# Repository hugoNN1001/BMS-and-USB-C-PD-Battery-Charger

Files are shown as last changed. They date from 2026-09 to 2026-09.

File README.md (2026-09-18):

# What is it?

This is a **BMS board** I designed for UNSW Bluesat's Cubesat as part of the **Australian Universities Rocket Competition (AURC)** which takes place in September 2027.

The **USB-C PD charger** is implemented on a separate board due to time constraint before the competition deadline.

The **BQ7791501** is a 3-5 cell stackable, ultra-low power battery pack protector with autonomous cell-balancing and hibernate mode. **Hibernate mode** is important to conserve battery life during long transit and standby time until the launch signal.

<table>
  <tr>
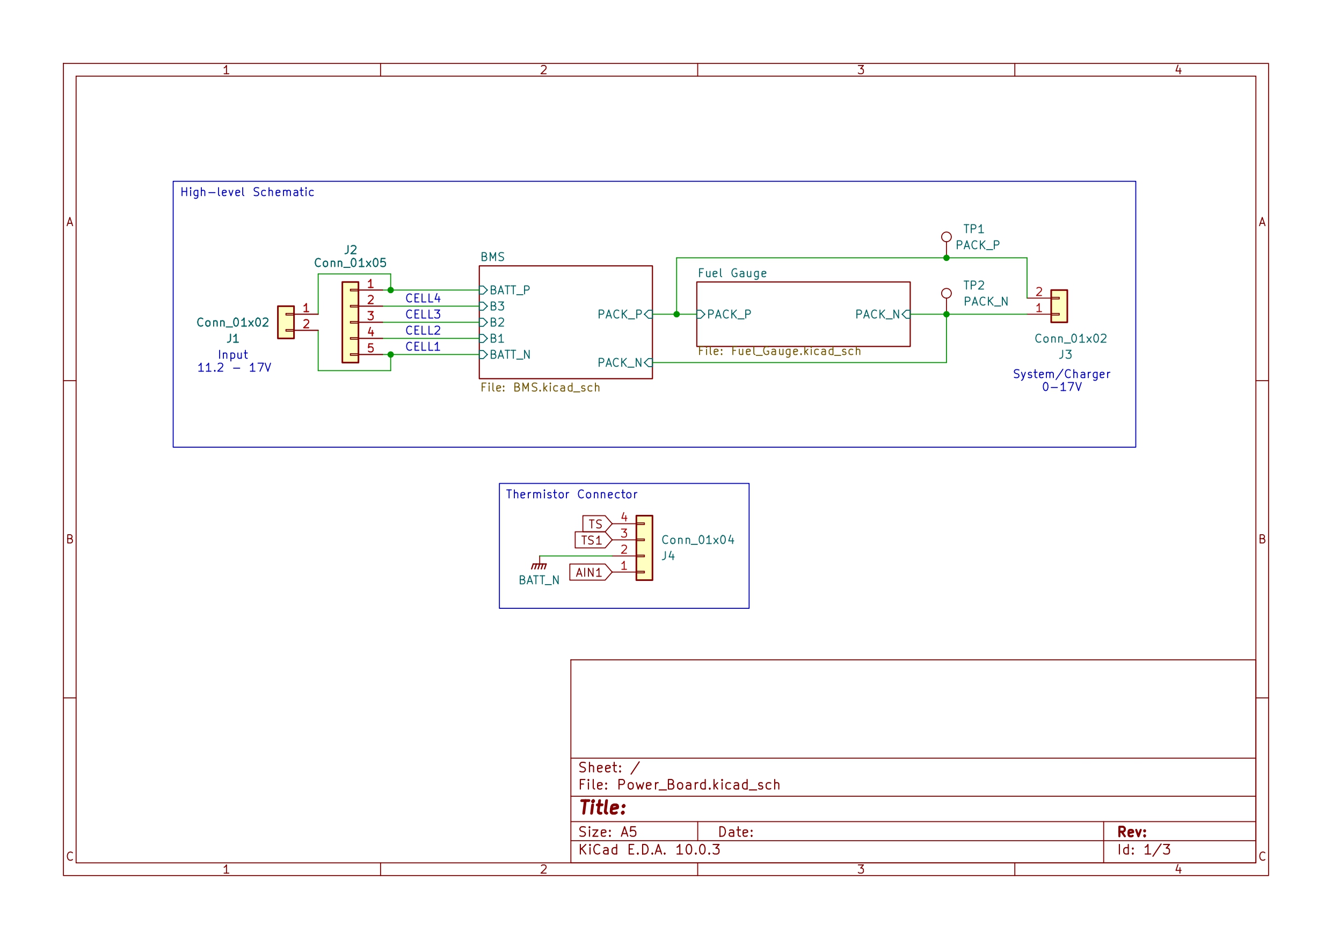
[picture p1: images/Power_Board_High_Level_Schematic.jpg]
    <td></td>
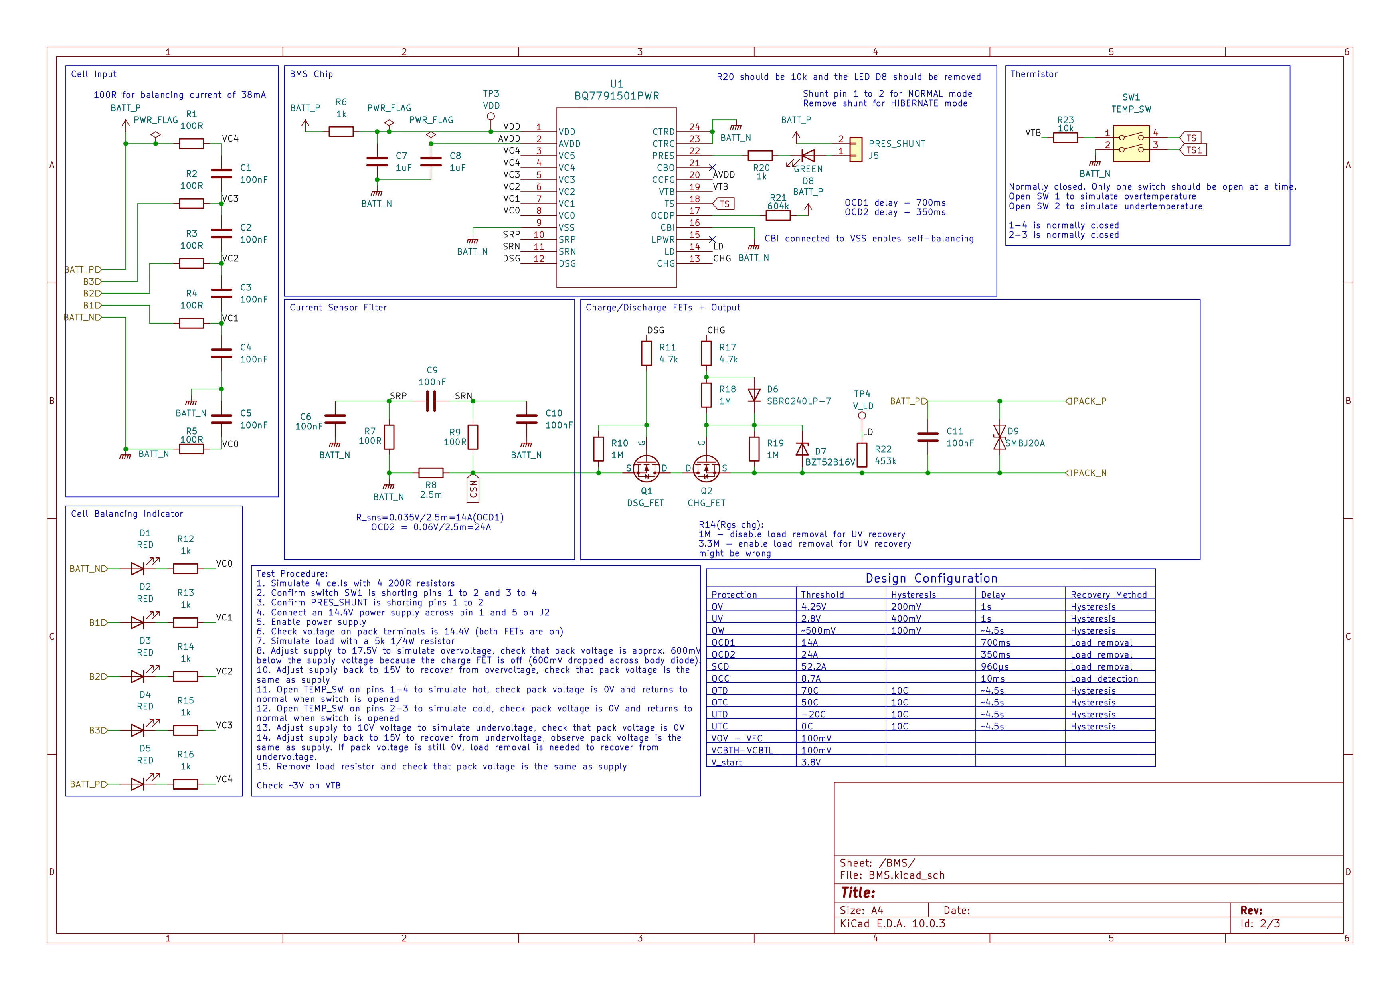
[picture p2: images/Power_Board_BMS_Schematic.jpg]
    <td></td>
  </tr>
  <tr>
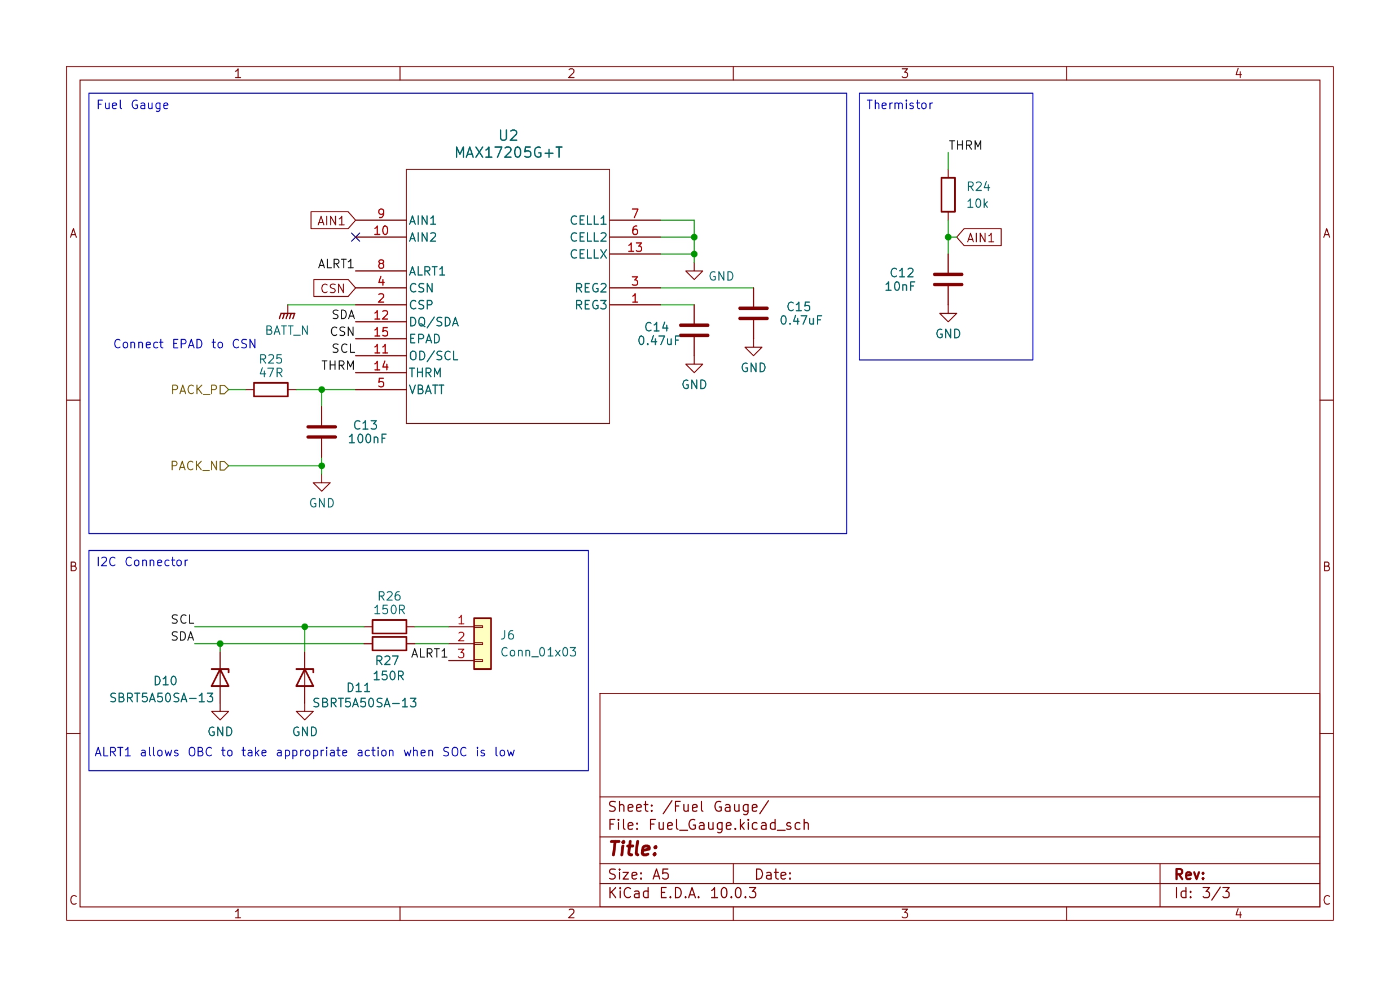
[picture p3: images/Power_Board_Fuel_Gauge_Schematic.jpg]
    <td></td>
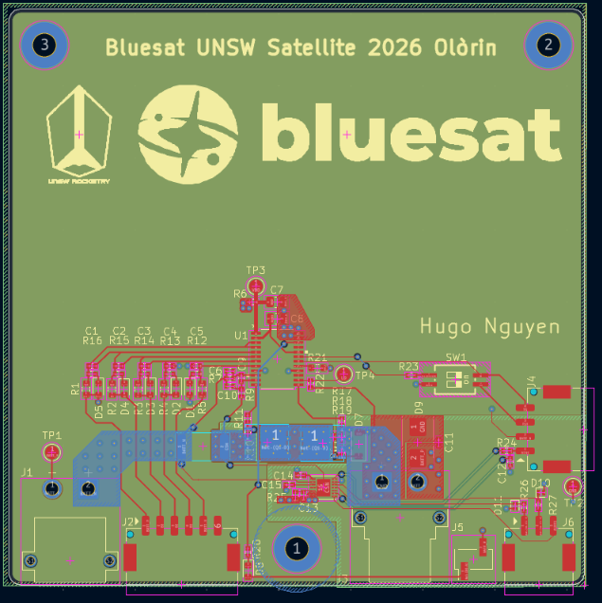
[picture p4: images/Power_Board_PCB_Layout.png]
    <td></td>
  </tr>
  <tr>
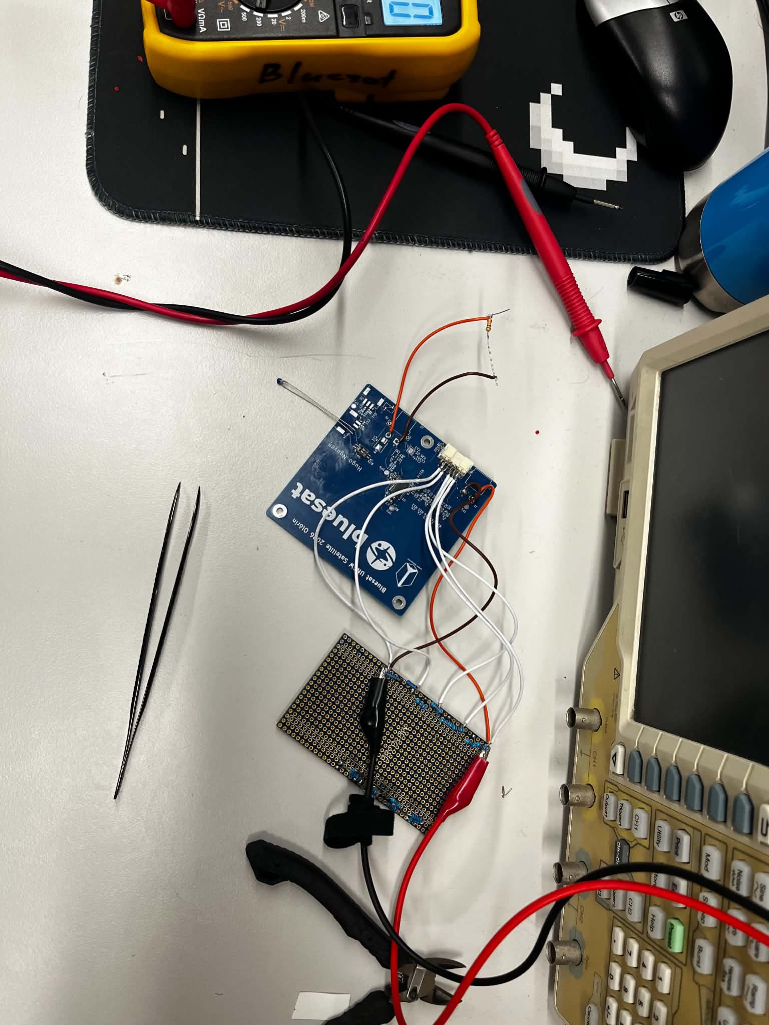
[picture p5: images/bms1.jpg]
    <td></td>
    <td></td>
  </tr>
</table>

## Technical

The two main loads are:
- **32 UV LEDs** to cure the resin of the Cubesat's 3D printer payload: In the worst-case, where battery pack voltage is near cut-off and LEDs are at set to output max power, they will draw around **8.5A** continuously
- **Stepper motor**: draws around 0.86A continuously and 1.06A peak

-> **Total current = 8.5A + 1.06A = 9.56A**

**OC1** is set to be **14A at 700ms**, this was chosen due to availability of the sense resistor values and should give us **~30% margin**. However, there is a tolerance of **± 20%** so it could be anywhere between **11.2A to 16.8A**.

**OC2**, as a result, is set at **24A at 350ms**.

The sense resistor is **2.5 mOhms with 0.5% tolerance** (instead of the regular 1%) for accurate current reading. **Kelvin connection** was used so the 2 sense traces carry minimum current. It is also rated up to **3W**, which is well above the calculated power dissipation of **1.44W** at OCD2 current of 24A.

A pair of switches was added to simulate a **hot/cold condition**, which assists in verifying the proper working of the BMS.

A **filter network** was placed close to the sense pins of the protector IC helps to filter noise out of the current reading.

A **jumper shunt** can be removed to enter **hibernate mode**.

## Status

The BMS board is working, **thoroughly verified**, in particular **OV, UV, OTD, UTD, OTC, UTC**.

**OCD1, OCD2, and OCC** is to be verified by using a larger sense resistor value to lower the overcurrent threshold. It is currently too high for the power supply's output current capability.

**Cell-balancing** has also been verified to work.

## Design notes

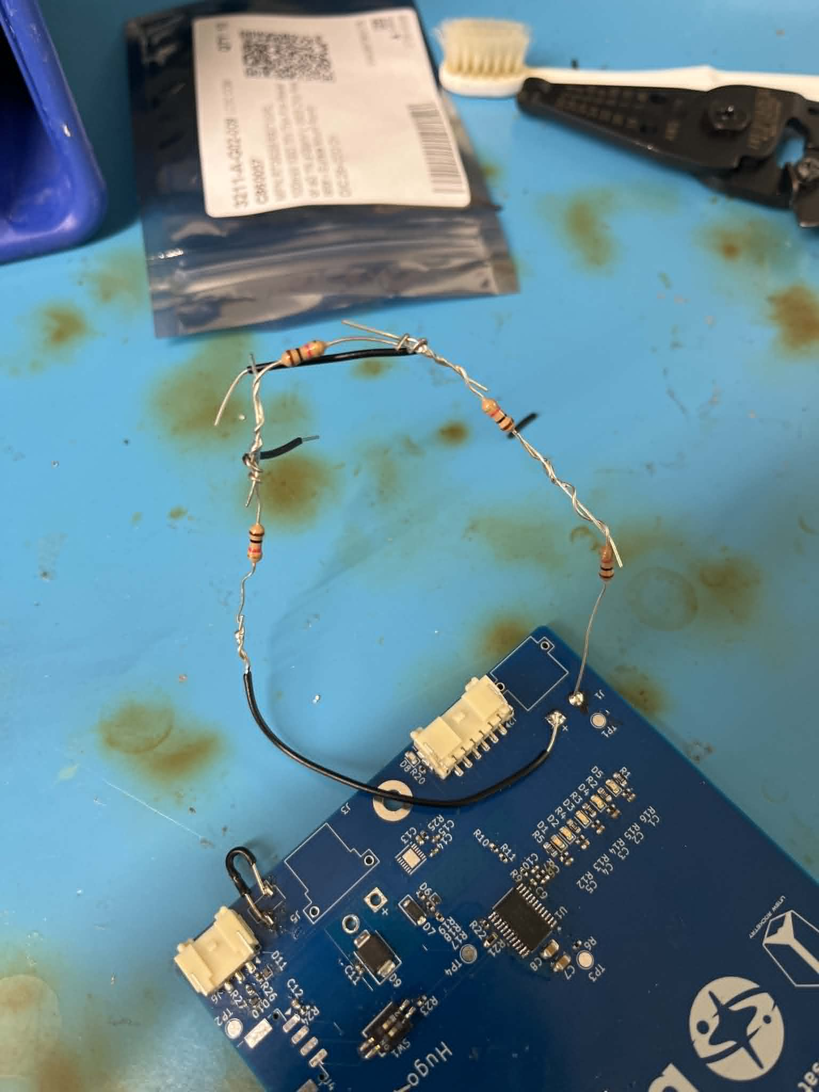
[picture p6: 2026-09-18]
images/bms4.jpg

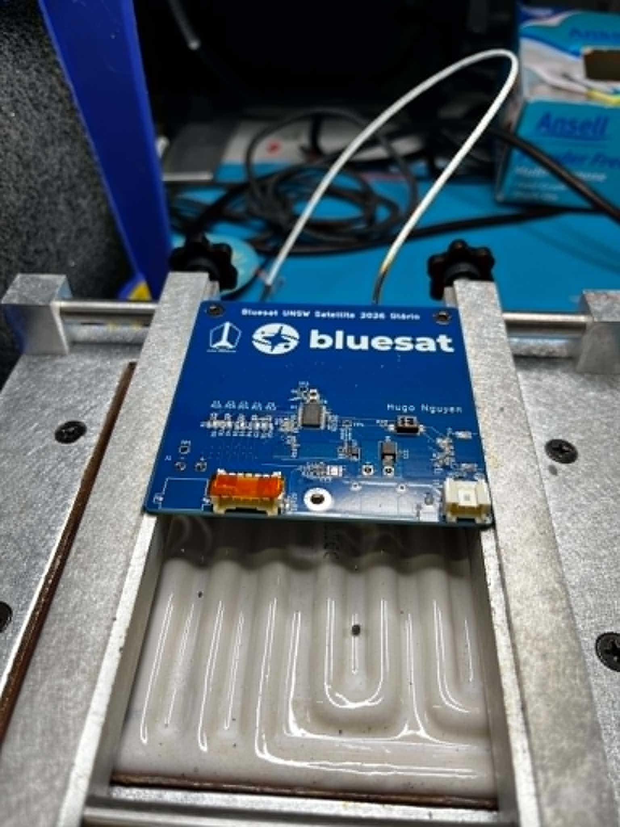
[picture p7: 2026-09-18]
images/bms5.jpg

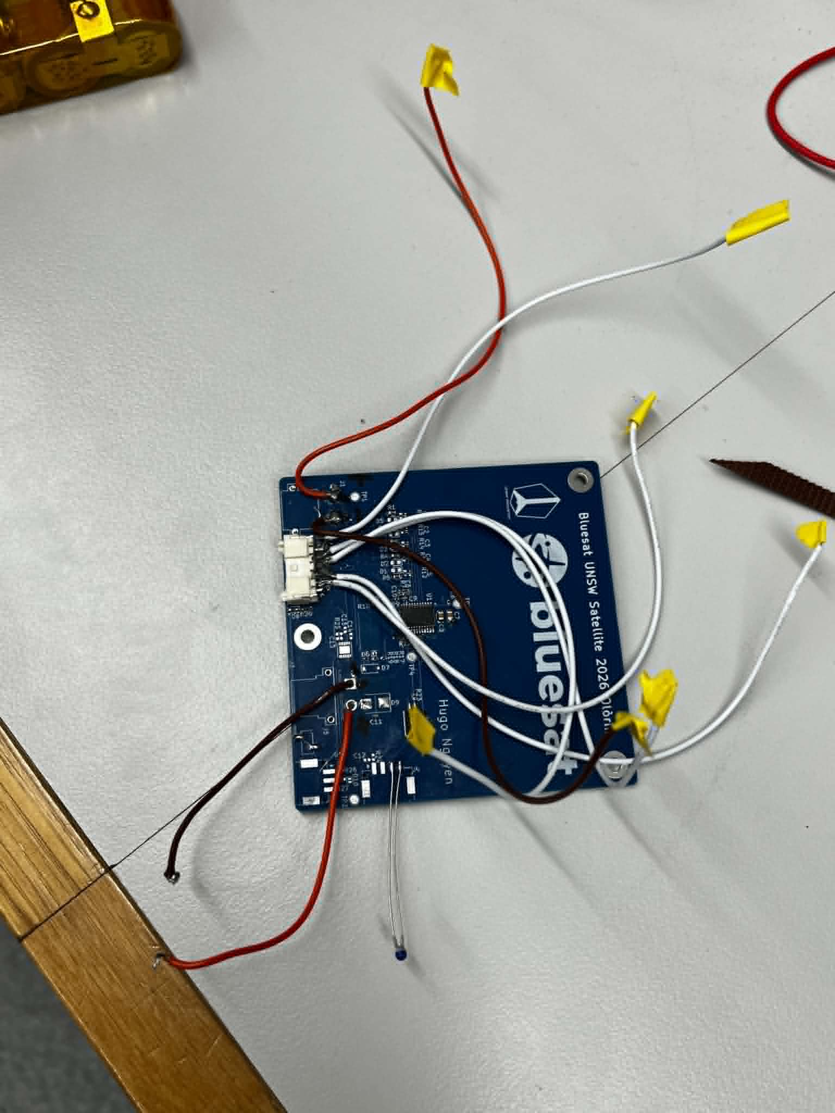
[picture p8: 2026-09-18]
images/bms2.jpg

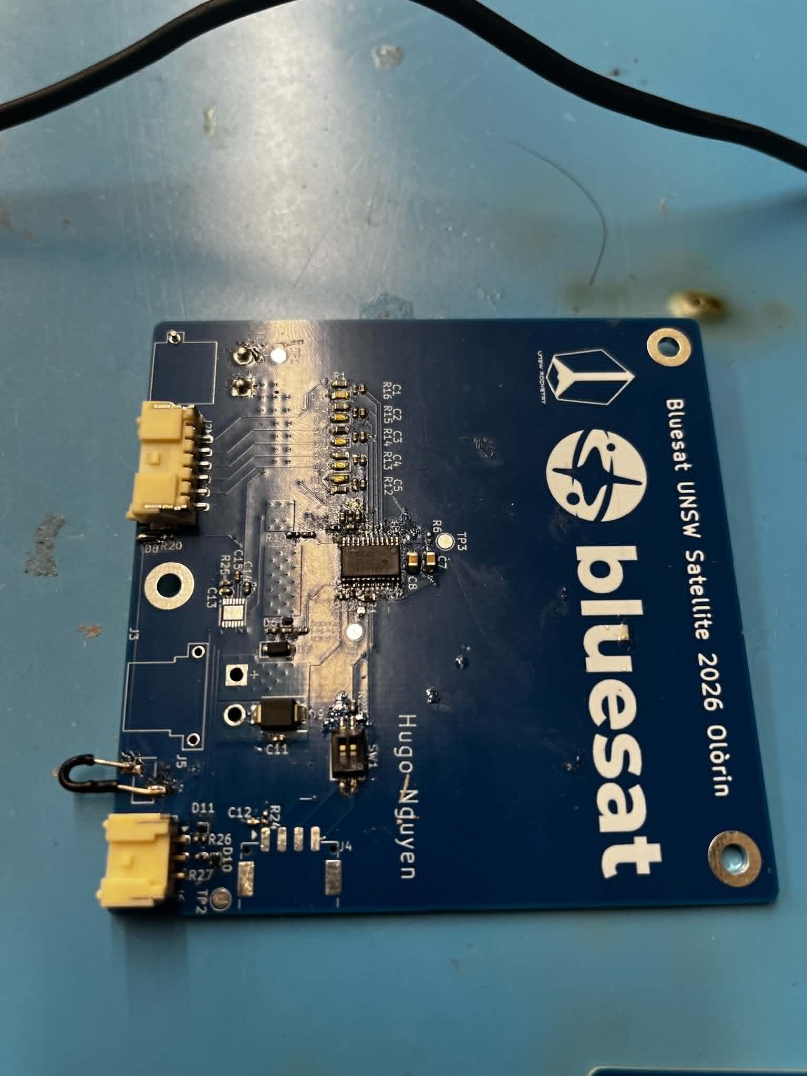
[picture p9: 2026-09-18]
images/bms3.jpg

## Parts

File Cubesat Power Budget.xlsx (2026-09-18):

Subsystem | Device | Component | Rail (V) | Quantity | Typ Current (mA) | Max Current (mA) | Ave Power (mW) |  | Note
Motor |  |  |  | Number of Phases | Phase Current (mA) | Max Current (mA) | Dissipated Power (mW) | Phase Resistant (Ω)
 |  |  |  | 2 | 1400 | 462 | 5174.4 | 2.64
Motor Total |  |  |  |  | 2800 | 924 | 10348.8 | 5.28
OBC
 | MCU | STM32G474RB | 3.3 | 1 |  |  | 0
 | Accelerometer | H3LIS331DL | 3.3 | 1 | 0.37 | 0.37 | 1.221 |  | ODR = 1000Hz
 | Barometer | BMP585 | 3.3 | 1 | 0.08 | 0.08 | 0.264
 | Temp Sensor | TMP1075D | 3.3 | 1 | 0.01 | 0.01 | 0.033 |  | SCL freq = 400kHz (fast mode)
 | Stepper Motor Driver |  |  |  |  |  | 0
 | GNSS | SAM-M10Q | 3.3 | 1 | 14.3 | 14.3 | 47.19
OBC Total
UV LCD Board |  |  |  |  |  | Estimated current drawn for 2*16 LEDs |  | add some redundency
 | LED Drivers & LEDS |  |  |  |  | 7.567567568 |  | 8A | https://www.ti.com/lit/ds/symlink/tlc5940.pdf
 |  |  |  |  |  |  |  |  | This is not accounting for dimming the LEDS
UV LCD Board Total
Number of Cells:
4
Cell Min Voltage:
2.8
 |  |  |  | https://www.littelfuse.com/media?itemid=75e32973-b177-4ee3-a0ff-cedaf1abdb93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
 |  |  | D9 | TVS diode | C364296 | not in stock
 |  |  | D7 | D7: Zener - 16V | C18195337 | not in stock
 |  |  | D6 | D6 | C460742
 |  |  |  | thermistor (0402) | C77131 | thermister (thru-hole) | C511390 | not in stock
 |  |  |  | sense resistor | C49164684 | not in stock |  | mouser | Yageo | 603-PA2512FKF7T0R004
 |  |  |  | 604k | C2484614 | not in stock
 |  |  |  | 450k | C5159688 | not in stock
 |  |  |  | nmos | C67862
 |  |  |  | low rds on
 |  |  |  | vgs
 |  |  |  | Id > ~15A
 |  |  |  | Vds > 16.8V
 |  |  |  | fuel gauge ic | C7220642 | not in stock
 |  |  |  | 470nF | C92361 | not in stock

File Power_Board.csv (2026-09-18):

Reference | Qty | Value | DNP | Exclude from BOM | Exclude from Board | Footprint | Datasheet
C1,C2,C3,C4,C5,C6,C9,C10,C11,C13 | 10 | 100nF |  |  |  | Capacitor_SMD:C_0603_1608Metric
C7,C8 | 2 | 1uF |  |  |  | Capacitor_SMD:C_0805_2012Metric
C12 | 1 | 10nF |  |  |  | Capacitor_SMD:C_0402_1005Metric
C14,C15 | 2 | 0.47uF |  |  |  | Capacitor_SMD:C_0603_1608Metric
D1,D2,D3,D4,D5 | 5 | RED |  |  |  | LED_SMD:LED_0402_1005Metric
D6 | 1 | SBR0240LP-7 |  |  |  | Diode_SMD:D_SOD-882
D7 | 1 | BZT52B16V |  |  |  | Diode_SMD:D_SOD-123
D8 | 1 | GREEN |  |  |  | LED_SMD:LED_0603_1608Metric
D9 | 1 | SMBJ20A |  |  |  | Diode_SMD:D_SMB | https://www.littelfuse.com/media?itemid=75e32973-b177-4ee3-a0ff-cedaf1abdb93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
D10,D11 | 2 | SBRT5A50SA-13 |  |  |  | Diode_SMD:D_SOD-882
J1 | 1 | Conn_01x02 |  |  |  | Footprint_Lib:AMASS_XT30PW-F
J2,J5 | 2 | Conn_01x03 |  |  |  | Footprint_Lib:SM03B-PASS
J3 | 1 | Conn_01x02 |  |  |  | Footprint_Lib:AMASS_XT30PW-M
J4 | 1 | Conn_01x02 |  |  |  | Connector_PinHeader_2.54mm:PinHeader_1x02_P2.54mm_Vertical_SMD_Pin1Left
Q1 | 1 | DSG_FET |  |  |  | Footprint_Lib:PQFN_5x6mm_E_DGS | https://ngspice.sourceforge.io/docs/ngspice-html-manual/manual.xhtml#cha_MOSFETs
Q2 | 1 | CHG_FET |  |  |  | Footprint_Lib:PQFN_5x6mm_E_DGS | https://ngspice.sourceforge.io/docs/ngspice-html-manual/manual.xhtml#cha_MOSFETs
R1,R2,R3,R4,R5,R7,R9 | 7 | 100R |  |  |  | Resistor_SMD:R_0402_1005Metric
R6,R12,R13,R14,R15,R16,R17,R20 | 8 | 1k |  |  |  | Resistor_SMD:R_0402_1005Metric
R8 | 1 | 2.5m |  |  |  | Resistor_SMD:R_2512_6332Metric
R10,R18,R19 | 3 | 1M |  |  |  | Resistor_SMD:R_0402_1005Metric
R11 | 1 | 4.7k |  |  |  | Resistor_SMD:R_0402_1005Metric
R21 | 1 | 604k |  |  |  | Resistor_SMD:R_0402_1005Metric
R22 | 1 | 450k |  |  |  | Resistor_SMD:R_0402_1005Metric
R23,R24 | 2 | 10k |  |  |  | Resistor_SMD:R_0402_1005Metric
R25 | 1 | 47R |  |  |  | Resistor_SMD:R_0402_1005Metric
R26,R27 | 2 | 150R |  |  |  | Resistor_SMD:R_0402_1005Metric
SW1 | 1 | SW_DIP_x02 |  |  |  | Footprint_Lib:XUNPU DSHP-02-TS-GER
TH1,TH2 | 2 | NCP15XH103F03RC |  |  |  | Resistor_SMD:R_0402_1005Metric
TP1 | 1 | PACK_P |  |  |  | TestPoint:TestPoint_Pad_D2.0mm
TP2 | 1 | PACK_N |  |  |  | TestPoint:TestPoint_Pad_D2.0mm
TP3 | 1 | V_BATT |  |  |  | TestPoint:TestPoint_Pad_D2.0mm
TP4 | 1 | AVDD |  |  |  | TestPoint:TestPoint_Pad_D2.0mm
TP5 | 1 | VDD |  |  |  | TestPoint:TestPoint_Pad_D2.0mm
TP6 | 1 | V_LD |  |  |  | TestPoint:TestPoint_Pad_D2.0mm
TP7 | 1 | VTS |  |  |  | TestPoint:TestPoint_Pad_D2.0mm
U1 | 1 | BQ7791501PWR |  |  |  | Footprint_Lib:TSSOP24_PW_TEX | https://www.ti.com/lit/gpn/bq77915
U2 | 1 | MAX17205G+T |  |  |  | Footprint_Lib:21-0137_T1433-2C_MXM | MAX17205G+T

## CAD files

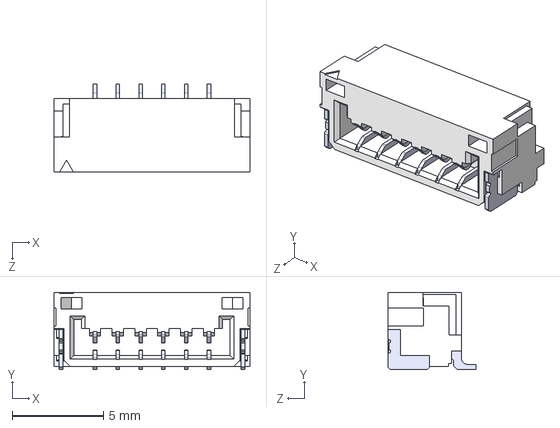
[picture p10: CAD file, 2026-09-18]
Power_Board_Misc/3D_Models/SM06B-GHS-TB.step
10.8 x 4.25 x 4.85 mm
SMxB-GHS-TB_06
pin x 6

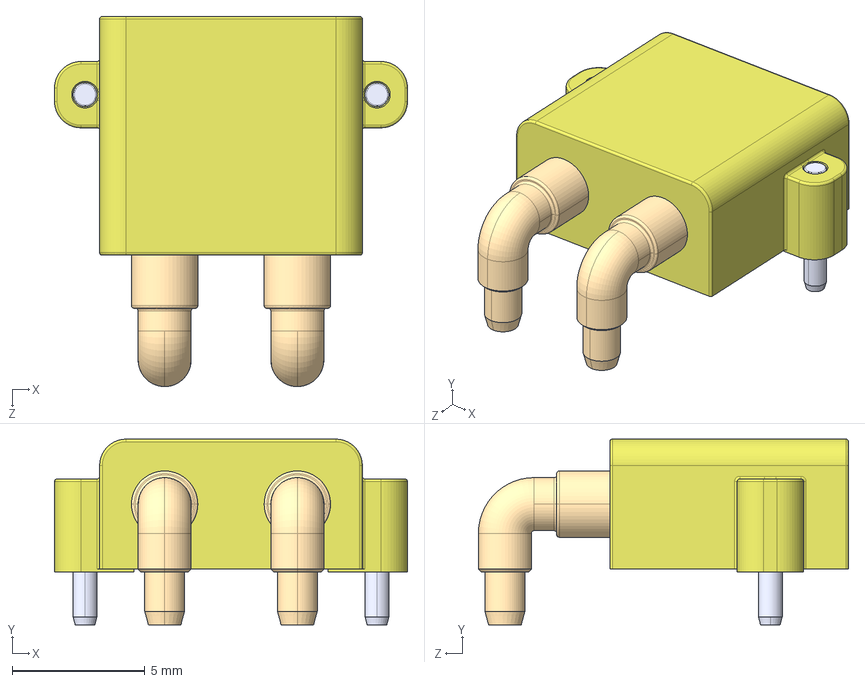
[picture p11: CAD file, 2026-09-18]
Power_Board_Misc/3D_Models/XT30PW-M.step
13.3 x 7.00 x 14.0 mm

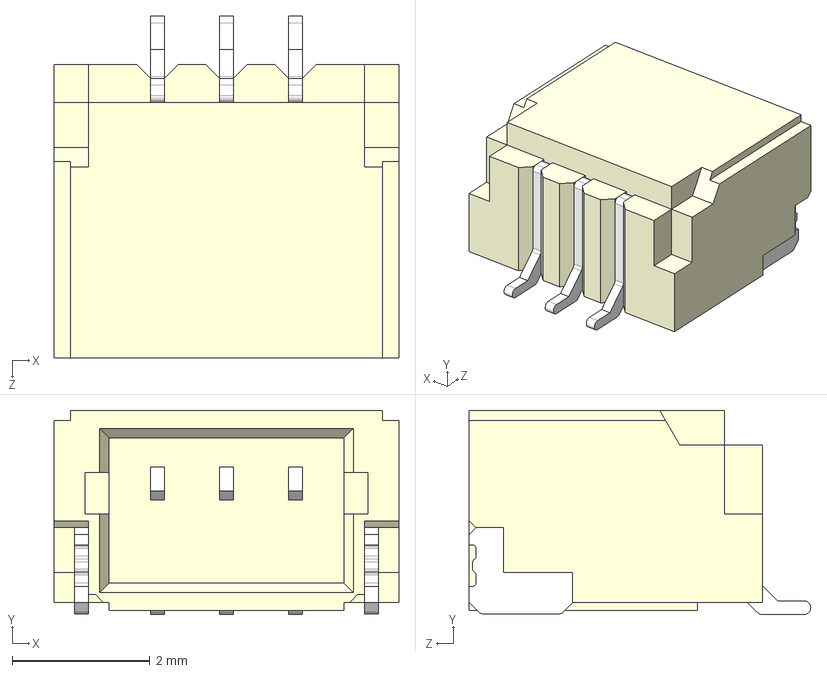
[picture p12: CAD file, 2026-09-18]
Power_Board_Misc/3D_Models/SM03B-SRSS-TB(LF)(SN)--3DModel-STEP-56544.STEP
5.00 x 2.96 x 4.95 mm

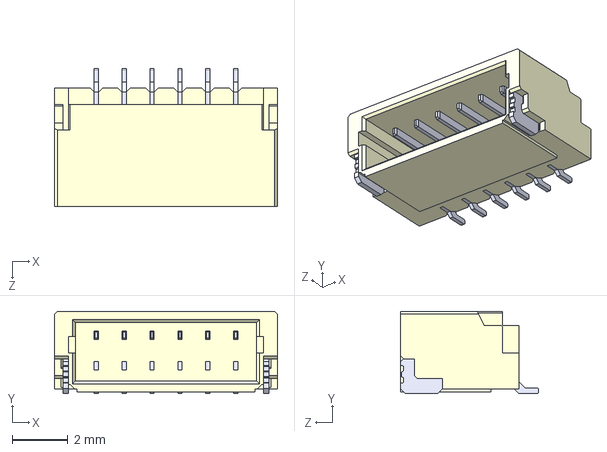
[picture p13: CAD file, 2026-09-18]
Power_Board_Misc/3D_Models/SM06B-SRSS-TB(LF)(SN)--3DModel-STEP-269445.STEP
8.00 x 2.95 x 4.95 mm

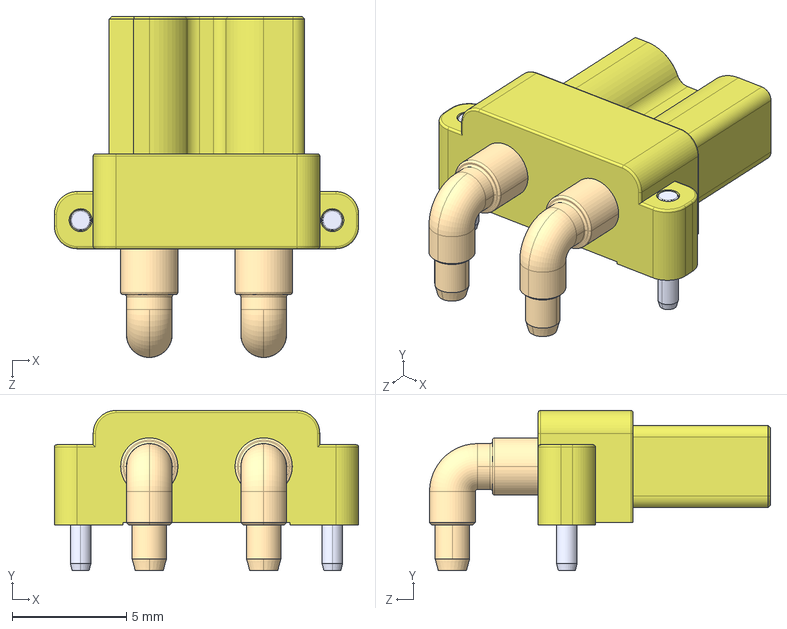
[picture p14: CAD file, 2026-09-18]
Power_Board_Misc/3D_Models/XT30PW-F.step
13.3 x 7.00 x 14.9 mm

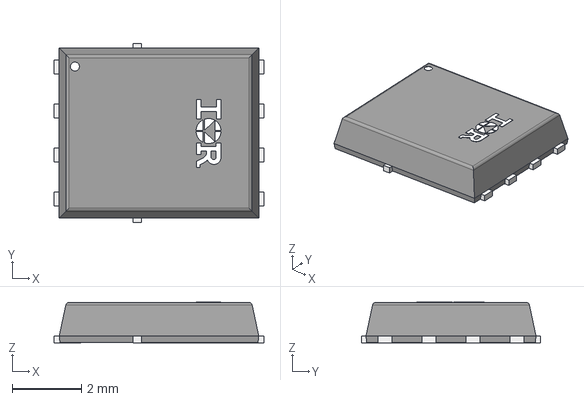
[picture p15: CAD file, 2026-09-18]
Power_Board_Misc/3D_Models/infineon-pg-tdson-8-907-3d-stp-package-en (1).stp
6.05 x 5.15 x 1.18 mm

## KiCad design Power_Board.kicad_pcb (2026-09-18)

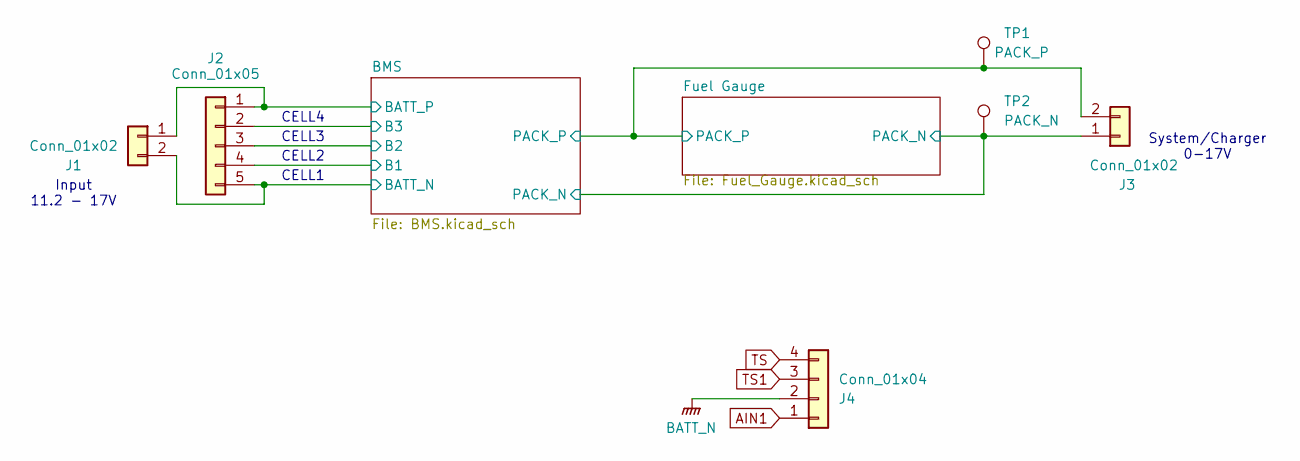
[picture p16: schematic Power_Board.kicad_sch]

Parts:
J1: Conn_01x02; AMASS_XT30PW-M
J2: Conn_01x05; SM06B-PASS
J3: Conn_01x02; AMASS_XT30PW-F
J4: Conn_01x04; SM04B-PASS
TP1: PACK_P; TestPoint_Pad_D2.0mm
TP2: PACK_N; TestPoint_Pad_D2.0mm

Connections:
/BMS/B1: J2.4; also elsewhere on the board
/BMS/B2: J2.3; also elsewhere on the board
/BMS/B3: J2.2; also elsewhere on the board
AIN1: J4.1; also elsewhere on the board
BATT_N: J1.2, J2.5, J4.2; also elsewhere on the board
BATT_P: J1.1, J2.1, J3.2, TP1.1 (1_1); also elsewhere on the board
GND: J3.1, TP2.1 (1_1); also elsewhere on the board
TS: J4.4; also elsewhere on the board
TS1: J4.3; also elsewhere on the board

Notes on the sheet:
CELL4
CELL3
CELL1
CELL2
System/Charger 0-17V
Input 11.2 - 17V

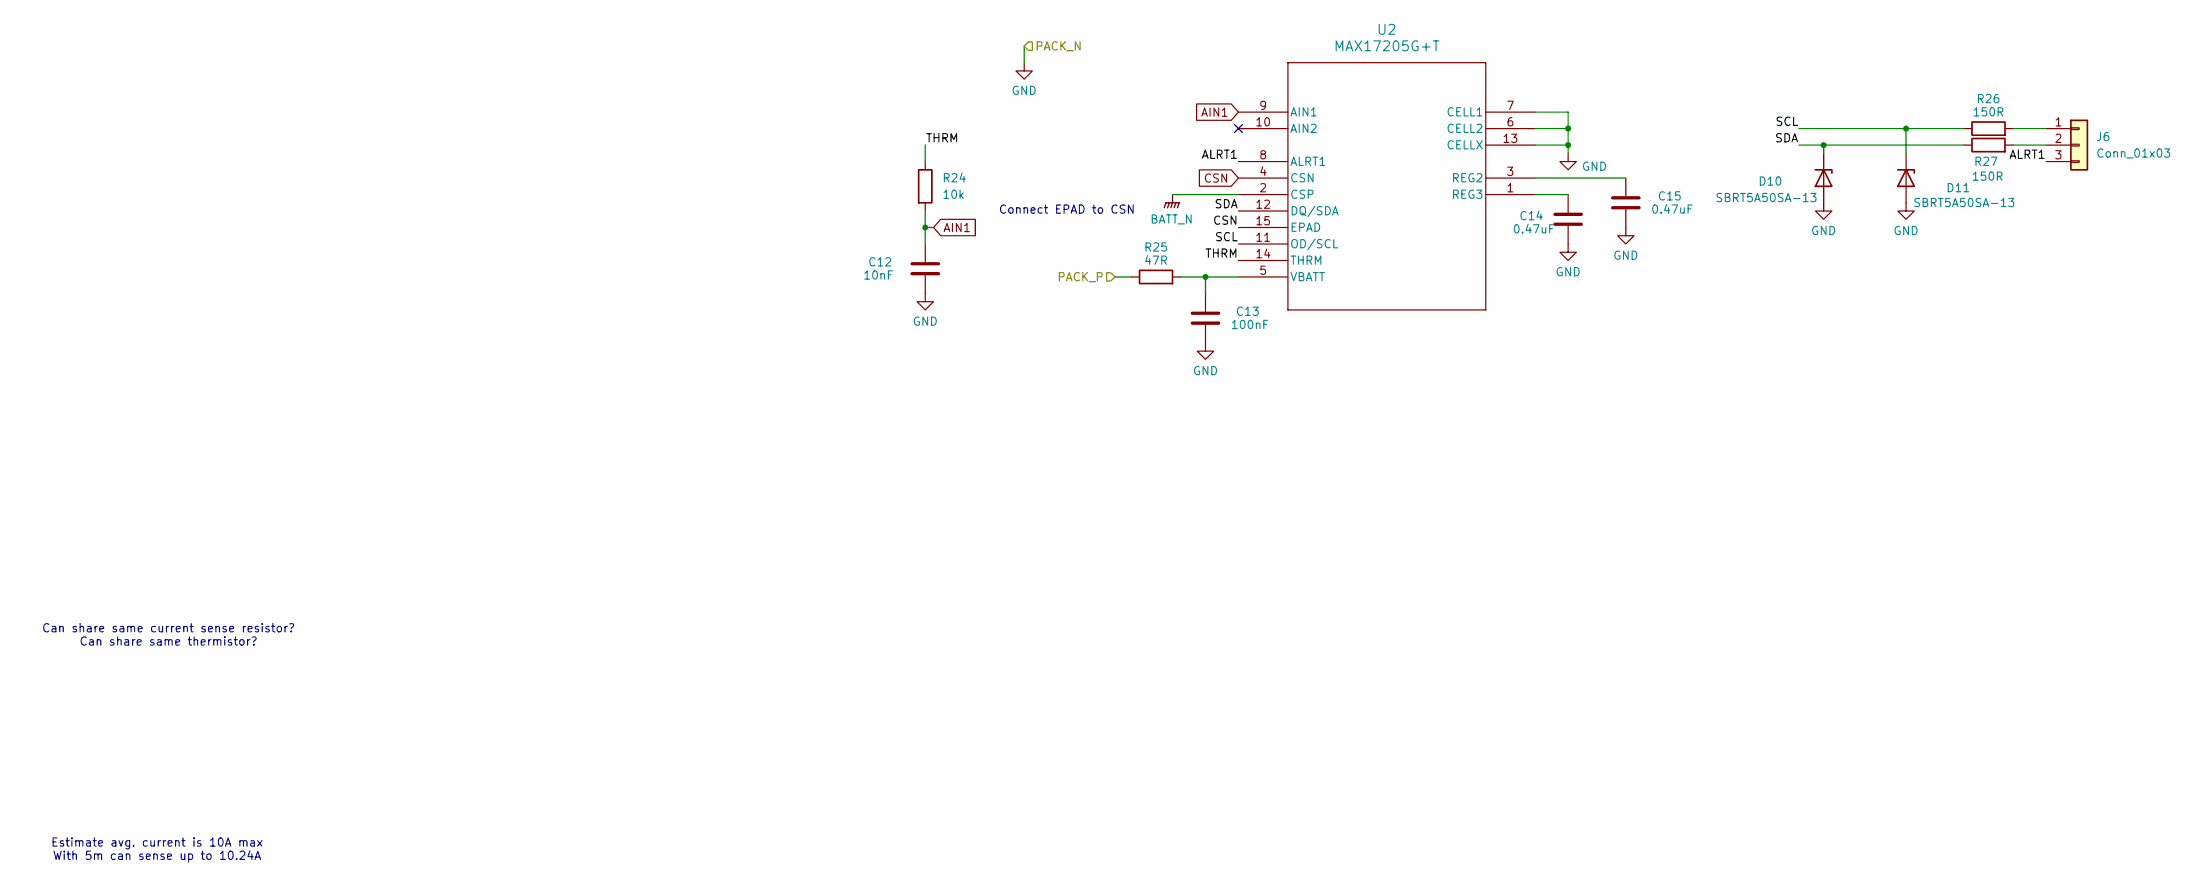
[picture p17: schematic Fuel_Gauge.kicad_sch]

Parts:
C12: 10nF; C_0402_1005Metric
C13: 100nF; C_0402_1005Metric
C14, C15: 0.47uF; C_0402_1005Metric
D10, D11: SBRT5A50SA-13; D_SOD-882
J6: Conn_01x03; SM03B-PASS
R24: 10k; R_0402_1005Metric
R25: 47R; R_0402_1005Metric
R26, R27: 150R; R_0402_1005Metric
U2: MAX17205G+T; 21-0137_T1433-2C_MXM

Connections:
/Fuel Gauge/ALRT1: J6.3, U2.8 (ALRT1)
/Fuel Gauge/SCL: D11.1 (K), R26.1, U2.11 (OD/SCL)
/Fuel Gauge/SDA: D10.1 (K), R27.1, U2.12 (DQ/SDA)
/Fuel Gauge/THRM: R24.1, U2.14 (THRM)
AIN1: C12.1, R24.2, U2.9 (AIN1); also elsewhere on the board
BATT_N: U2.2 (CSP); also elsewhere on the board
BATT_P: R25.1; also elsewhere on the board
CSN: U2.4 (CSN), U2.15 (EPAD); also elsewhere on the board
GND: C12.2, C13.2, C14.2, C15.2, D10.2 (A), D11.2 (A), U2.6 (CELL2), U2.7 (CELL1), U2.13 (CELLX); also elsewhere on the board
unnamed: J6.1, R26.2
unnamed: J6.2, R27.2
unnamed: C15.1, U2.3 (REG2)
unnamed: C14.1, U2.1 (REG3)
unnamed: C13.1, R25.2, U2.5 (VBATT)

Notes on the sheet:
Connect EPAD to CSN
Can share same current sense resistor? Can share same thermistor?
Estimate avg. current is 10A max With 5m can sense up to 10.24A

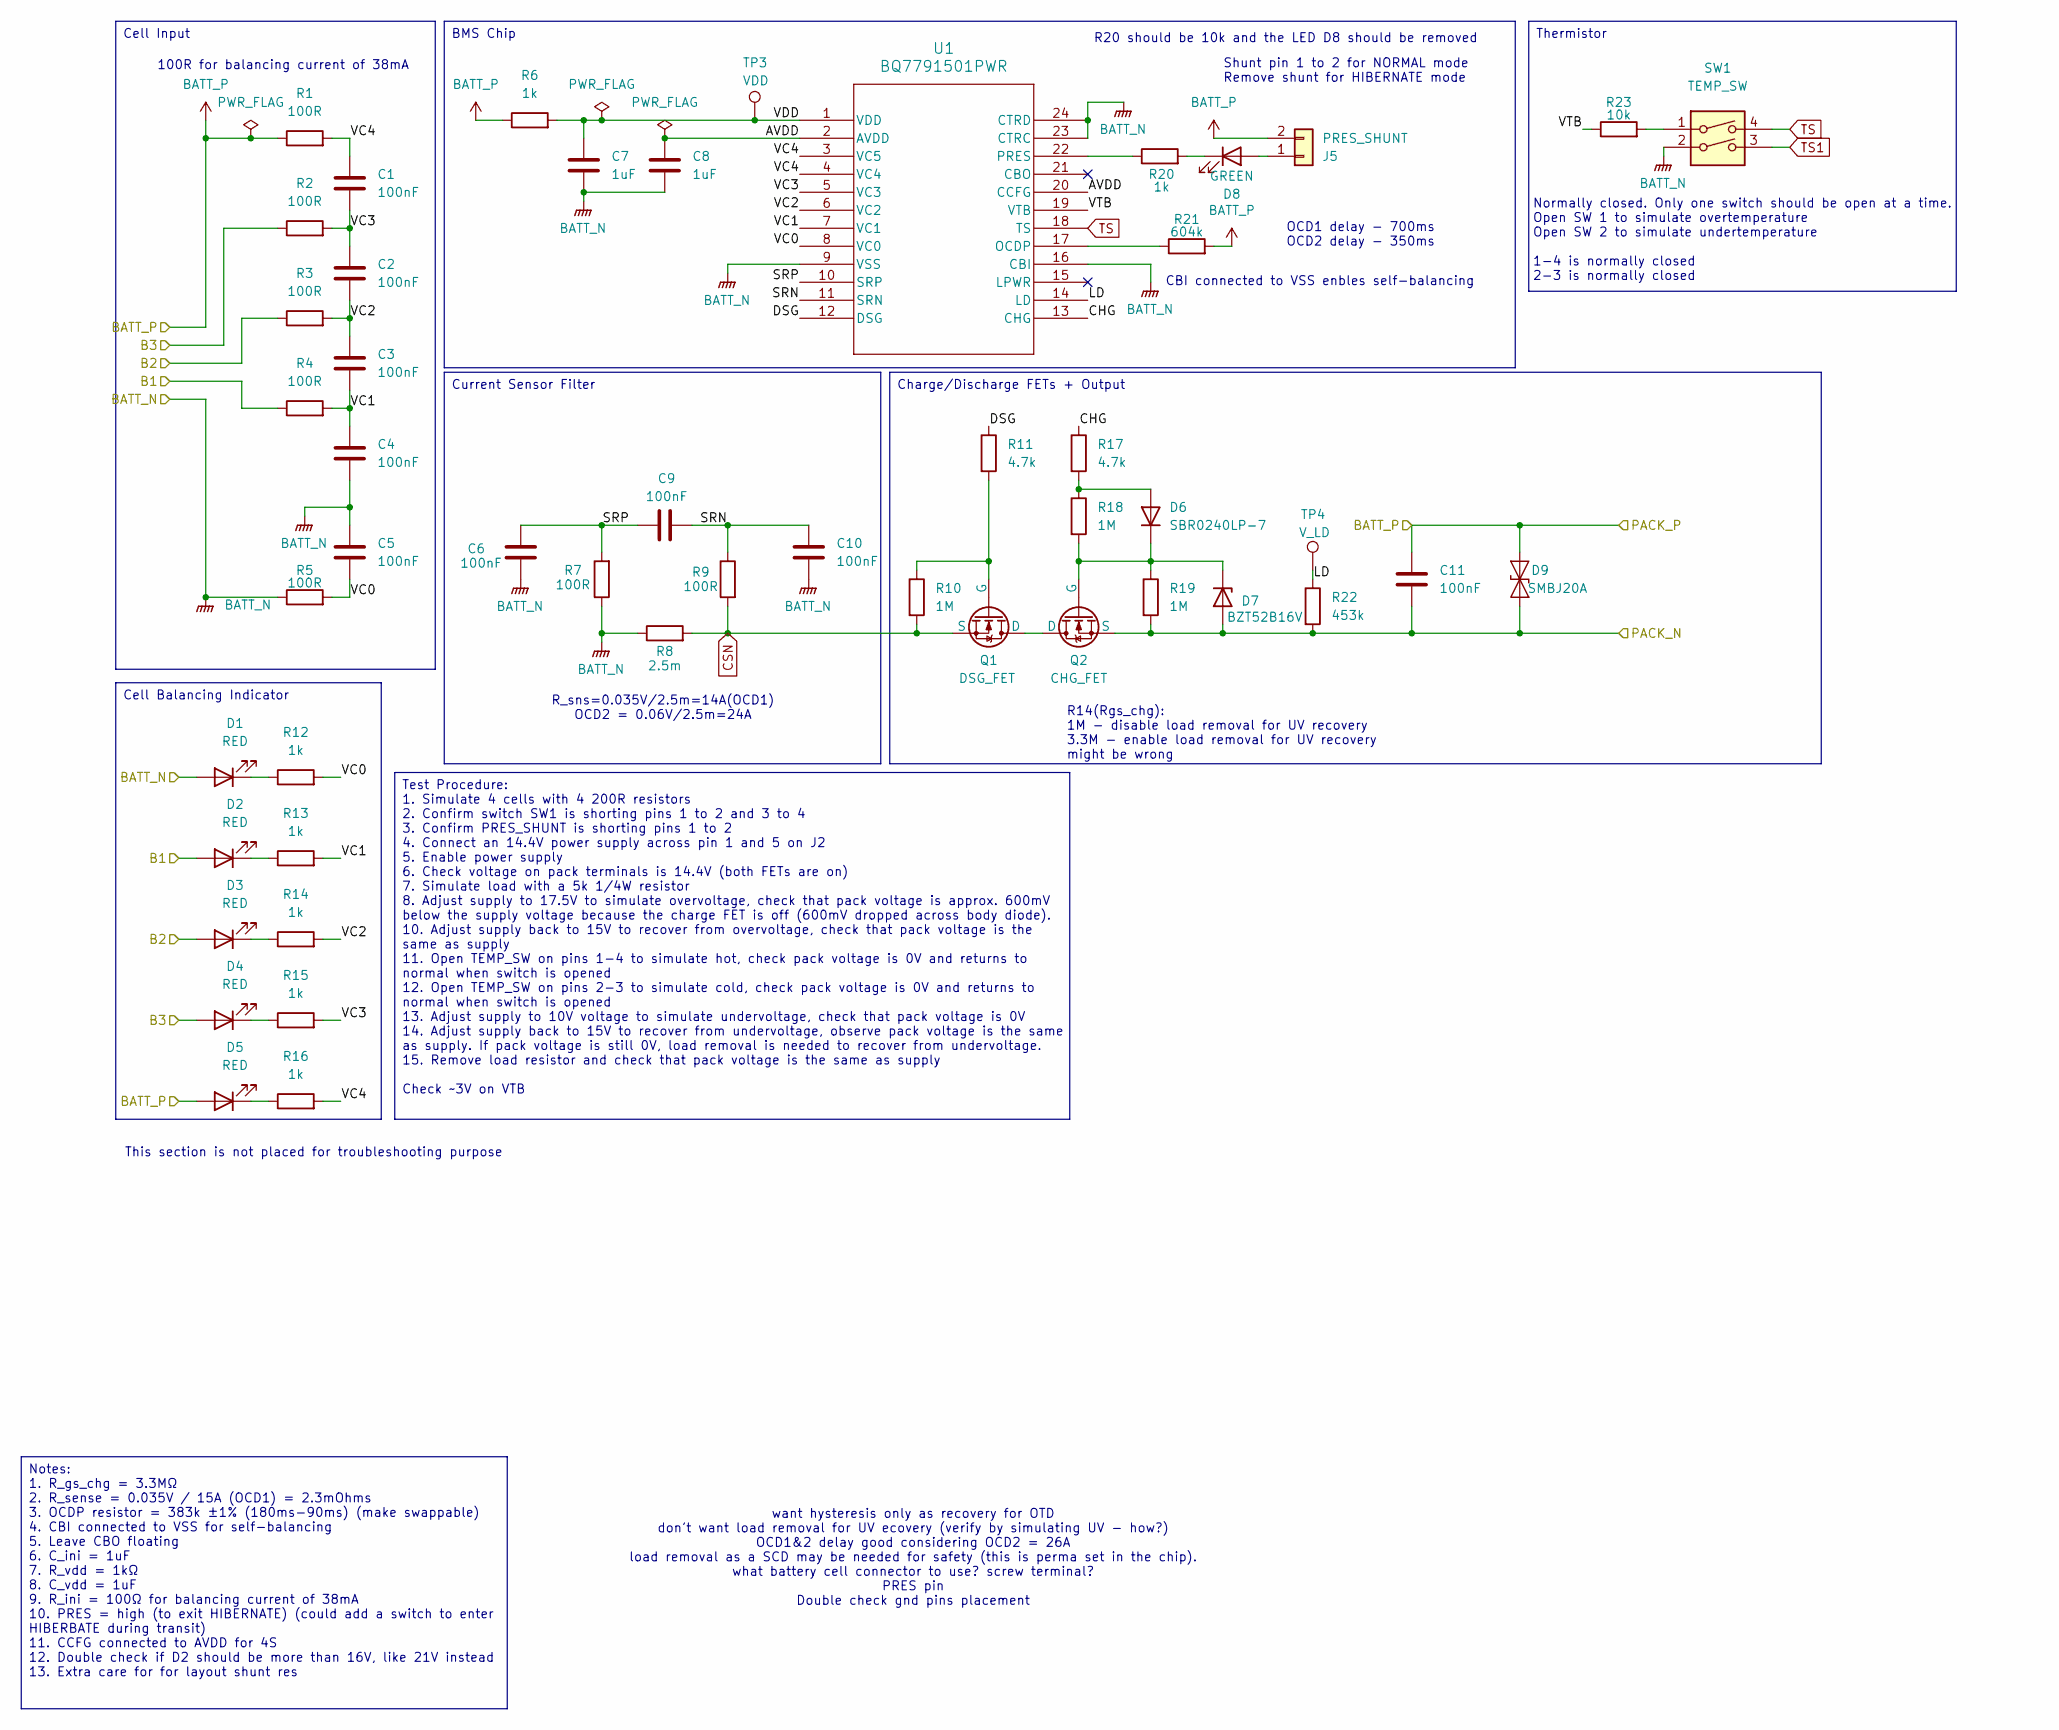
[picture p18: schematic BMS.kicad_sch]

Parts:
C1, C2, C3, C4, C5, C6, C9, C10, C11: 100nF; C_0402_1005Metric
C7, C8: 1uF; C_0805_2012Metric
D1, D2, D3, D4, D5: RED; LED_0603_1608Metric
D6: SBR0240LP-7; D_SOD-882
D7: BZT52B16V; D_SOD-123
D8: GREEN; LED_0603_1608Metric
D9: SMBJ20A; D_SMB
J5: PRES_SHUNT; PinHeader_1x02_P2.54mm_Vertical_SMD_Pin1Left
Q1: DSG_FET; PQFN_5x6mm_E_DGS
Q2: CHG_FET; PQFN_5x6mm_E_DGS
R1, R2, R3, R4, R5: 100R; R_0603_1608Metric
R6, R12, R13, R14, R15, R16, R20: 1k; R_0402_1005Metric
R7, R9: 100R; R_0402_1005Metric
R8: 2.5m; R_2512_6332Metric
R10, R18, R19: 1M; R_0402_1005Metric
R11, R17: 4.7k; R_0402_1005Metric
R21: 604k; R_0603_1608Metric
R22: 453k; R_0402_1005Metric
R23: 10k; R_0402_1005Metric
SW1: TEMP_SW; XUNPU DSHP-02-TS-GER
TP3: VDD; TestPoint_Pad_D2.0mm
TP4: V_LD; TestPoint_Pad_D2.0mm
U1: BQ7791501PWR; TSSOP24_PW_TEX

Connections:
/BMS/AVDD: C8.1, U1.2 (AVDD), U1.20 (CCFG)
/BMS/B1: D2.2 (A), R4.1; also elsewhere on the board
/BMS/B2: D3.2 (A), R3.1; also elsewhere on the board
/BMS/B3: D4.2 (A), R2.1; also elsewhere on the board
/BMS/CHG: R17.1, U1.13 (CHG)
/BMS/DSG: R11.1, U1.12 (DSG)
/BMS/LD: R22.1, TP4.1 (1_1), U1.14 (LD)
/BMS/SRN: C9.2, C10.1, R9.1, U1.11 (SRN)
/BMS/SRP: C6.1, C9.1, R7.2, U1.10 (SRP)
/BMS/VC0: C5.2, R5.2, R12.2, U1.8 (VC0)
/BMS/VC1: C3.2, C4.1, R4.2, R13.2, U1.7 (VC1)
/BMS/VC2: C2.2, C3.1, R3.2, R14.2, U1.6 (VC2)
/BMS/VC3: C1.2, C2.1, R2.2, R15.2, U1.5 (VC3)
/BMS/VC4: C1.1, R1.2, R16.2, U1.3 (VC5), U1.4 (VC4)
/BMS/VDD: C7.1, R6.2, TP3.1 (1_1), U1.1 (VDD)
/BMS/VTB: R23.1, U1.19 (VTB)
BATT_N: C4.2, C5.1, C6.2, C7.2, C8.2, C10.2, D1.2 (A), R5.1, R7.1, R8.1, SW1.2, U1.9 (VSS), U1.16 (CBI), U1.23 (CTRC), U1.24 (CTRD); also elsewhere on the board
BATT_P: C11.1, D5.2 (A), D9.2 (A2), J5.2, R1.1, R6.1, R21.2; also elsewhere on the board
CSN: Q1.3 (S), R8.2, R9.2, R10.2; also elsewhere on the board
GND: C11.2, D7.2 (A), D9.1 (A1), Q2.3 (S), R19.2, R22.2; also elsewhere on the board
unnamed: D1.1 (K), R12.1
unnamed: D2.1 (K), R13.1
unnamed: D3.1 (K), R14.1
unnamed: D4.1 (K), R15.1
unnamed: D5.1 (K), R16.1
unnamed: D6.2 (A), R17.2, R18.1
unnamed: D6.1 (K), D7.1 (K), Q2.2 (G), R18.2, R19.1
unnamed: D8.2 (A), J5.1
unnamed: D8.1 (K), R20.2
unnamed: Q1.1 (D), Q2.1 (D)
unnamed: Q1.2 (G), R10.1, R11.2
unnamed: R23.2, SW1.1
unnamed: R21.1, U1.17 (OCDP)
unnamed: R20.1, U1.22 (PRES)
TS: SW1.4, U1.18 (TS); also elsewhere on the board
TS1: SW1.3; also elsewhere on the board

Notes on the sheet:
Shunt pin 1 to 2 for NORMAL mode Remove shunt for HIBERNATE mode
want hysteresis only as recovery for OTD don't want load removal for UV ecovery (verify by simulating UV - how?) OCD1&2 delay good considering OCD2 = 26A load removal as a SCD may be needed for safety (this is perma set in the chip). what battery cell connector to use? screw terminal? PRES pin Doub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
Normally closed. Only one switch should be open at a time. Open SW 1 to simulate overtemperature Open SW 2 to simulate undertemperature 1-4 is normally closed 2-3 is normally closed
100R for balancing current of 38mA
OCD1 delay - 700ms OCD2 delay - 350ms
R14(Rgs_chg): 1M - disable load removal for UV recovery 3.3M - enable load removal for UV recovery might be wrong
R20 should be 10k and the LED D8 should be removed
CBI connected to VSS enbles self-balancing
R_sns=0.035V/2.5m=14A(OCD1) OCD2 = 0.06V/2.5m=24A
This section is not placed for troubleshooting purpose
Test Procedure: 1. Simulate 4 cells with 4 200R resistors 2. Confirm switch SW1 is shorting pins 1 to 2 and 3 to 4 3. Confirm PRES_SHUNT is shorting pins 1 to 2 4. Connect an 14.4V power supply across pin 1 and 5 on J2 5. Enable power supply 6. Check voltage on pack terminals is 14.4V (both FETs ar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
Notes: 1. R_gs_chg = 3.3MΩ 2. R_sense = 0.035V / 15A (OCD1) = 2.3mOhms 3. OCDP resistor = 383k ±1% (180ms-90ms) (make swappable) 4. CBI connected to VSS for self-balancing 5. Leave CBO floating 6. C_ini = 1uF 7. R_vdd = 1kΩ 8. C_vdd = 1uF 9. R_ini = 100Ω for balancing current of 38mA 10. PRES = hig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
Cell Input
Cell Balancing Indicator
Thermistor
Current Sensor Filter
BMS Chip
Charge/Discharge FETs + Output

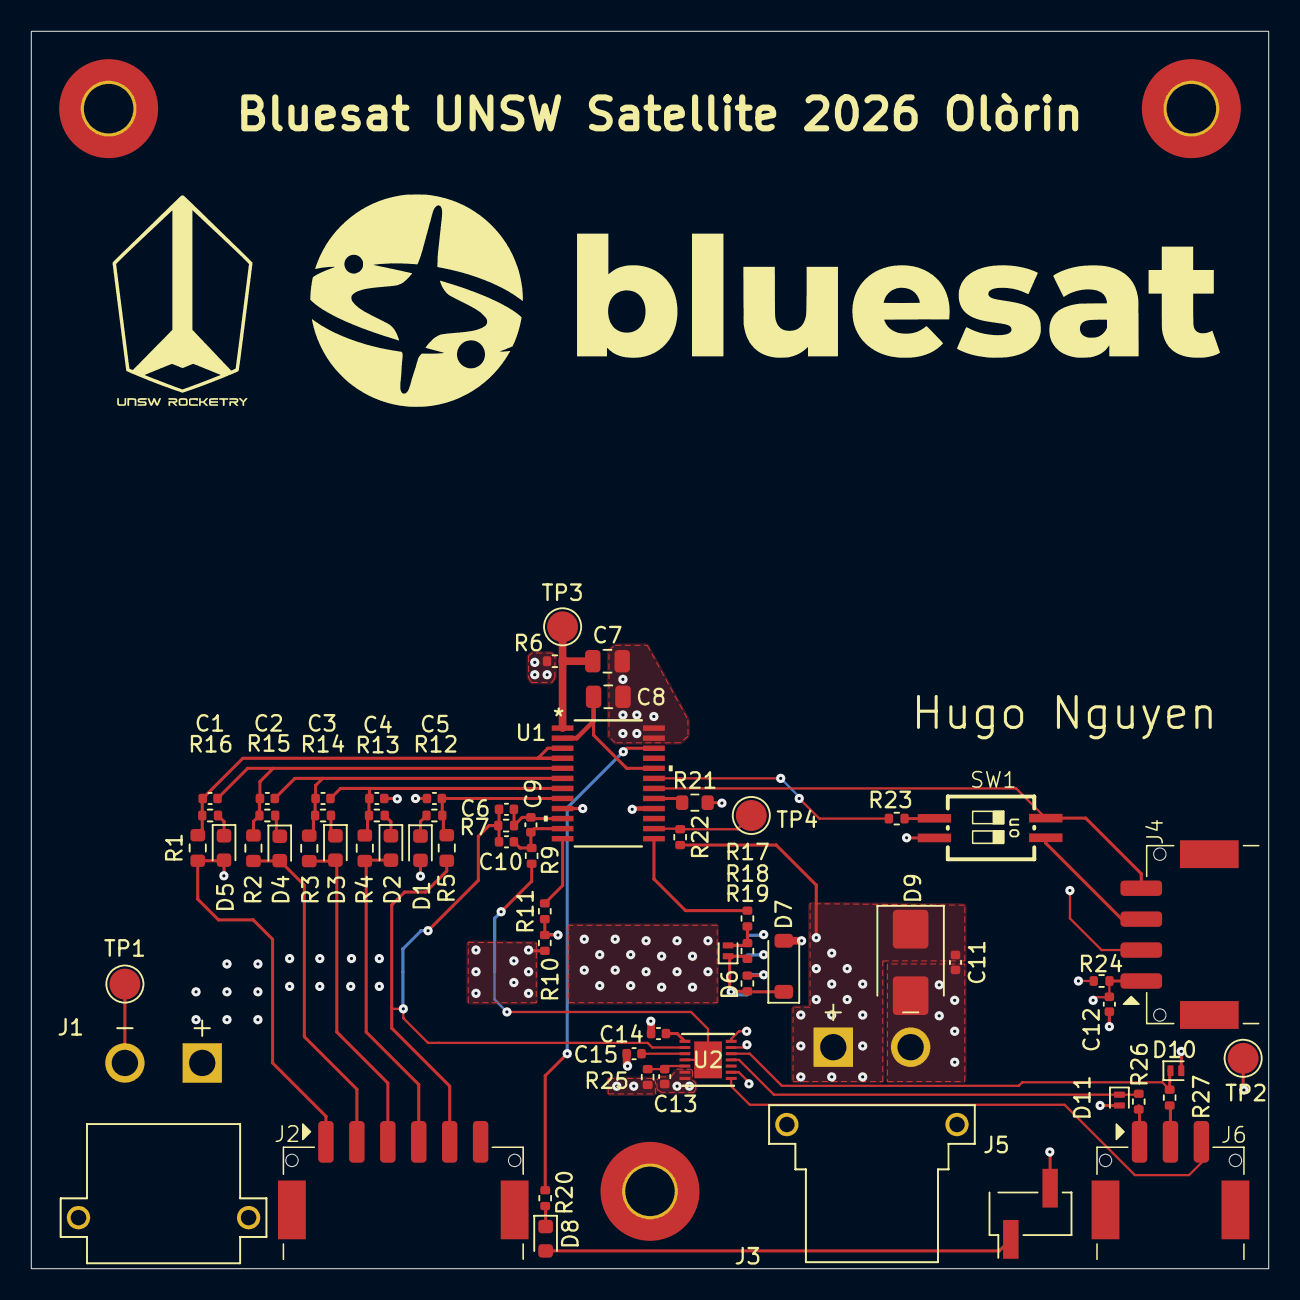
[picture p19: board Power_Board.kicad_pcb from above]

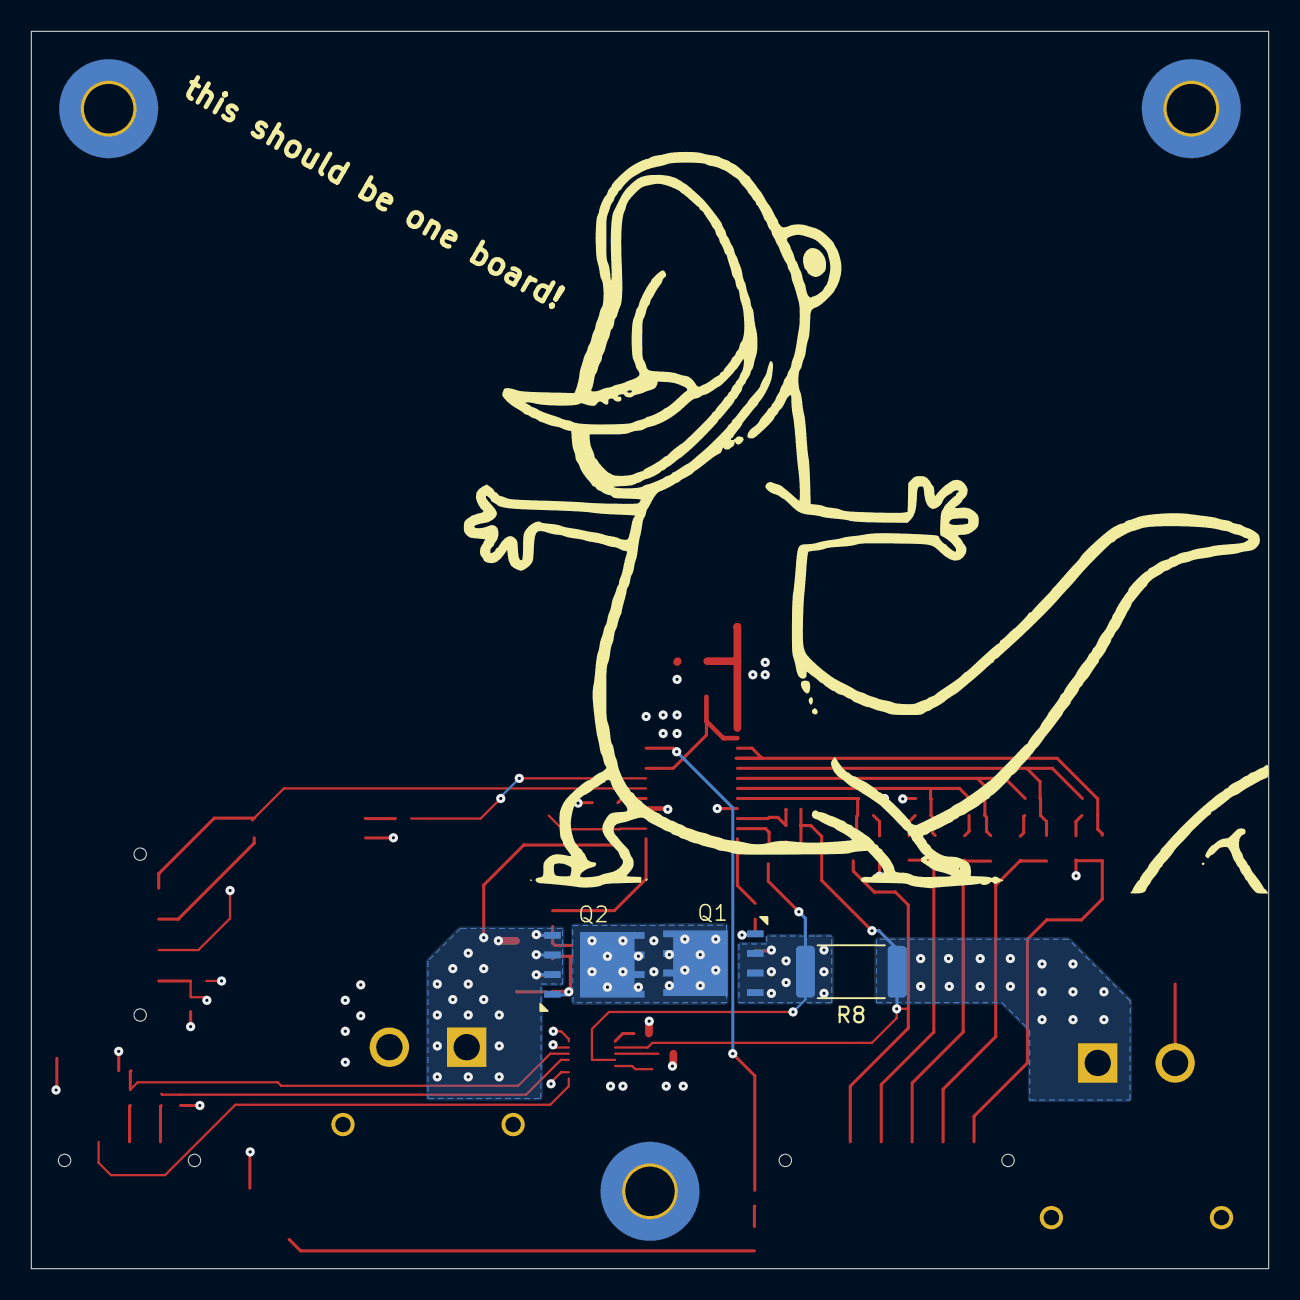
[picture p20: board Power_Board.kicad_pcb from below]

Board: 4 copper layers, 80.0 x 80.0 mm, 68 parts (3 on the bottom side), 46 nets.
